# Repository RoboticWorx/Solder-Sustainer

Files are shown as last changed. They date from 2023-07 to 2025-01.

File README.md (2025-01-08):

# Solder_Sustainer
Files for my Solder Sustainer project.

Everything needed to build this project can be found on www.roboticworx.io for free! (https://roboticworx.io/blogs/projects/solder-sustainer)
Holding
MAIN

**_(Remember, you can download anything you'd like for yourself but you CAN'T sell it. All my work is licensed, thanks!)_**

Thanks for reading and happy making!

Best regards,
Justin

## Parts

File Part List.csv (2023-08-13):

 | From LCSC
Order Qty. | LCSC Part Number | Manufacture Part Number | Manufacturer | Package | Description | RoHS | Unit Price
3 | C383211 | LESD5D5.0CT1G | LRC | SOD-523 | Zener Diode 5.6V 18.6V 5V Bi-Directional SOD-523 ESD Protection Devices ROHS | YES | 0.0152
1 | C82544 | 1N5819HW-7-F | Diodes Incorporated | SOD-123 | Diode 40V 450mV@1A 1A SOD-123 Schottky Barrier Diodes (SBD) ROHS | YES | 0.0208
5 | C513772 | CS1005X7R104K500NR | Samwha Capacitor | 402 | 50V 100nF Capacitor ±10% 0402 Multilayer Ceramic Capacitors MLCC - SMD/SMT ROHS | YES | 0.0019
2 | C2912598 | HoAR0805-1/8W-5.1KR-0.1%-TCR25 | Milliohm | 805 | 5k1 Resistor 125mW Ceramic resistor ±25ppm/℃ ±0.1% 5.1kΩ 0805 Chip Resistor - Surface Mount ROHS | YES | 0.0506
1 | *OPTIONAL C2886570 | SK6812mini | OPSCO Optoelectronics | SMD | SMD Light Emitting Diodes (LED) ROHS | YES | 0.1927
2 | C2886903 | TL3305BF260QG | E-Switch | SMD | Switch NO 50mA 100MΩ 200000 Times 12V 260gf Brick nogging SPST SMD Tactile Switches ROHS | YES | 0.1807
1 | C2913202 | ESP32-S3-WROOM-1U-N16R8 | Espressif Systems | SMD,18x25.5mm | ESP32-S3-WROOM SMD,18x25.5mm WiFi Modules ROHS | YES | 5.1132
1 | *RESISTOR FOR PWR LED (3V3/.02A) C2849095 | PTFR0805B200RP9 | Resistor.Today | 805 | 200ohm Resistor 0.13W Thin Film Resistor ±25ppm/℃ ±0.1% 200Ω 0805 Chip Resistor - Surface Mount ROHS | YES | 0.1403
1 | C2765186 | TYPE-C 16PIN 2MD(073) | SHOU HAN | SMD | USB-C Connector 5A 1 Surface Mount 16P Female -25℃~+85℃ Type-C SMD USB Connectors ROHS | YES | 0.0523
1 | C5120765 | AMS1117-3.3V | MSKSEMI | SOT-223 | 1A Fixed 3.3V Positive 18V SOT-223 Linear Voltage Regulators (LDO) ROHS | YES | 0.0427
 | From DigiKey
 | Digi-Key Part # | Manufacturer Part Number | Description | Backorder | Unit Price
4 | 1276-6454-1-ND | CL21A106KAYNNNG | 10uF/25V Capacitor CAP CER 10UF 25V X5R 0805 | 0 | $0.07
1 | 1276-1034-1-ND | CL10A105KO8NNNC | 1uF/16V Capacitor CAP CER 1UF 16V X5R 0603 | 0 | $0.01
1 | RNCP0603FTD10K0CT-ND | RNCP0603FTD10K0 | 10kohm Resistor RES 10K OHM 1% 1/8W 0603 | 0 | $0.02
 | Other | Amazon Link
1 | 100uF Capacitor (Could also be SMD) | https://www.amazon.com/BOJACK-Electrolytic-Capacitor-Assortment-0-1uF%25EF%25BC%258D1000uF/dp/B07PBQXQNQ?amp;keywords=capacitor+kit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
2 | 2N2222 Transistors or other NPN transistor | https://www.amazon.com/BOJACK-General-Purpose-Transistors-Assortment/dp/B07T5166B8?amp;keywords=transistor+kit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
1 | A4988 Stepper Motor Driver | https://www.amazon.com/gp/product/B07BND65C8?amp;psc=1&linkId=e62621cc388ef44c6753cd39ee17c85e&camp=1789&creative=9325
1 | MT3608 Voltage Step-Up Regulator | https://www.amazon.com/gp/product/B089JYBF25?amp;psc=1&linkId=d4404d10156ef6bd04675826cf120e4c&camp=1789&creative=9325

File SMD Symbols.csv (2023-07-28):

Reference | Value | Footprint | Datasheet | SNAPEDA_PACKAGE_ID | SNAPEDA_PN | STANDARD | Qty
A1 | Pololu_Breakout_A4988 | Module:Pololu_Breakout-16_15.2x20.3mm | https://www.pololu.com/product/2980/pictures |  |  |  | 1
C1, C4, C5, C9 | 10uF/25V | Capacitor_SMD:C_0805_2012Metric_Pad1.18x1.45mm_HandSolder | ~ |  |  |  | 4
C2 | 1uF/16V | Capacitor_SMD:C_0603_1608Metric_Pad1.08x0.95mm_HandSolder | ~ |  |  |  | 1
C3, C6-C8, C10 | 0u1F/50V | Capacitor_SMD:C_0201_0603Metric_Pad0.64x0.40mm_HandSolder | ~ |  |  |  | 5
C11 | 100µF | Capacitor_THT:CP_Radial_D5.0mm_P2.50mm | ~ |  |  |  | 1
D1 | 1N5819HW-7-F | MyParts:SOD3715X145N |  |  |  | IPC-7351B | 1
D2-D4 | LESD5D5.0CT1G | MyParts:TVS_LESD5D5.0CT1G |  |  |  | Manufacturer Recommendations | 3
D5 | SK6812MINI | LED_SMD:LED_SK6812MINI_PLCC4_3.5x3.5mm_P1.75mm | https://cdn-shop.adafruit.com/product-files/2686/SK6812MINI_REV.01-1-2.pdf |  |  |  | 1
D6 | LED | LED_THT:LED_D3.0mm | ~ |  |  |  | 1
D7 | Apple Block | MyParts:Outlet Rectifier | ~ |  |  |  | 1
J1 | TYPE-C-31-M-12 | MyParts:HRO_TYPE-C-31-M-12 |  |  | TYPE-C-31-M-12 | Manufacturer Recommendations | 1
J2 | Conn_01x04_Pin | Connector_PinHeader_2.54mm:PinHeader_1x04_P2.54mm_Vertical | ~ |  |  |  | 1
Q1, Q2 | 2N2222 | Connector_PinHeader_2.00mm:PinHeader_1x03_P2.00mm_Vertical | http://www.onsemi.com/pub_link/Collateral/2N2219-D.PDF |  |  |  | 2
R1, R2 | 5k1 | Resistor_SMD:R_0805_2012Metric_Pad1.20x1.40mm_HandSolder | ~ |  |  |  | 2
R3 | 10k | Resistor_SMD:R_0805_2012Metric_Pad1.20x1.40mm_HandSolder | ~ |  |  |  | 1
R4 | 165 | Resistor_SMD:R_0603_1608Metric_Pad0.98x0.95mm_HandSolder | ~ |  |  |  | 1
S1 | TL3305BF260QG/BOOT | MyParts:SW_TL3305BF260QG |  |  | TL3305BF260QG | Manufacturer Recommendations | 1
S2 | TL3305BF260QG/RST | MyParts:SW_TL3305BF260QG |  |  | TL3305BF260QG | Manufacturer Recommendations | 1
U1 | ESP32-S3-WROOM-1-N16R2 | MyParts:XCVR_ESP32-S3-WROOM-1-N16R2 |  |  |  | Manufacturer Recommendations | 1
U2 | AMS1117-3.3 | MyParts:AMS1117-3.3 |  | 71280 | AMS1117-3.3 | IPC 7351B | 1
U3 | MT3608 | MyParts:MT3608 Breakout | https://www.olimex.com/Products/Breadboarding/BB-PWR-3608/resources/MT3608.pdf |  |  |  | 1
U4, U5 |  | MyParts:Touch Sensor |  |  |  |  | 2

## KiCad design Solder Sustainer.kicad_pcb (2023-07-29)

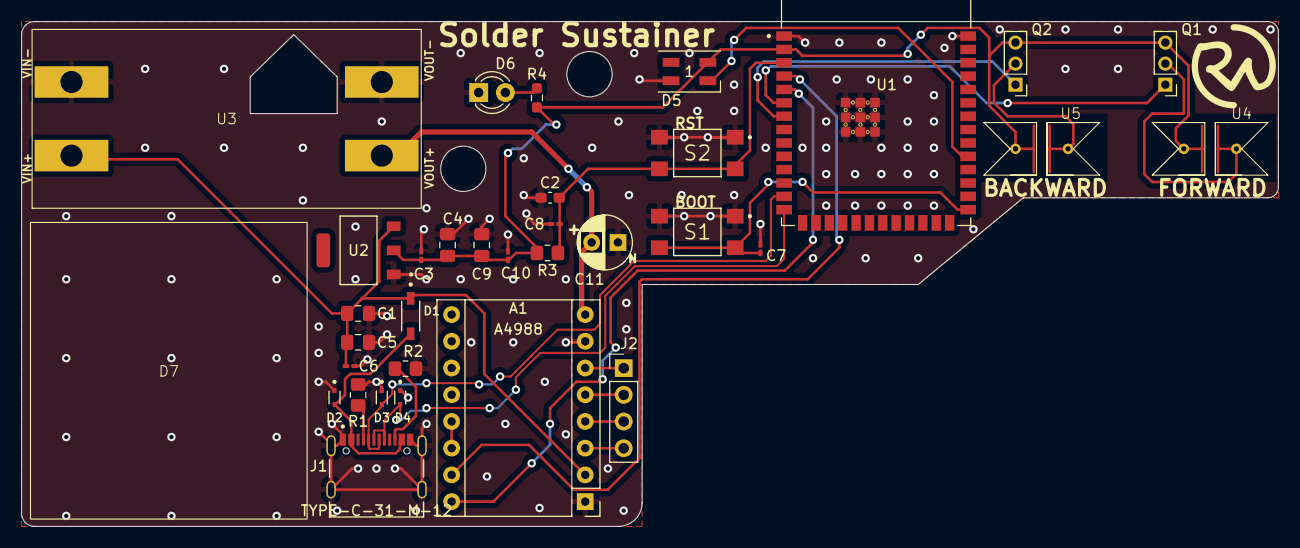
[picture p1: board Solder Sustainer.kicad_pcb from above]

Board: 2 copper layers, 119.5 x 48.0 mm, 34 parts (0 on the bottom side), 24 nets.

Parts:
A1: Pololu_Breakout_A4988; Pololu_Breakout-16_15.2x20.3mm
C1, C4, C5, C9: 10uF/25V; C_0805_2012Metric_Pad1.18x1.45mm_HandSolder
C2: 1uF/16V; C_0603_1608Metric_Pad1.08x0.95mm_HandSolder
C3, C6, C7, C8, C10: 0u1F/50V; C_0201_0603Metric_Pad0.64x0.40mm_HandSolder
C11: 100µF; CP_Radial_D5.0mm_P2.50mm
D1: 1N5819HW-7-F; SOD3715X145N
D2, D3, D4: LESD5D5.0CT1G; TVS_LESD5D5.0CT1G
D5: SK6812MINI; LED_SK6812MINI_PLCC4_3.5x3.5mm_P1.75mm
D6: LED; LED_D3.0mm
D7: Apple Block; Outlet Rectifier
J1: TYPE-C-31-M-12; HRO_TYPE-C-31-M-12
J2: Conn_01x04_Pin; PinHeader_1x04_P2.54mm_Vertical
Q1, Q2: 2N2222; PinHeader_1x03_P2.00mm_Vertical
R1, R2: 5k1; R_0805_2012Metric_Pad1.20x1.40mm_HandSolder
R3: 10k; R_0805_2012Metric_Pad1.20x1.40mm_HandSolder
R4: 165; R_0603_1608Metric_Pad0.98x0.95mm_HandSolder
S1: TL3305BF260QG/BOOT; SW_TL3305BF260QG
S2: TL3305BF260QG/RST; SW_TL3305BF260QG
U1: ESP32-S3-WROOM-1-N16R2; XCVR_ESP32-S3-WROOM-1-N16R2
U2: AMS1117-3.3
U3: MT3608; MT3608 Breakout
U4, U5: Touch Sensor

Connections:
/CC1: J1.A5 (CC1), R1.1
/CC2: J1.B5 (CC2), R2.1
B_LOW: Q2.2 (B), U5.2 (OUT)
B_STATE: Q2.1 (E), U1.7 (IO7)
CHIP_PU: C2.2, C8.1, R3.1, S2.3, S2.4, U1.3 (EN)
D+: D4.2, J1.A6 (DP1), J1.B6 (DP2), U1.14 (IO20)
D-: D3.2, J1.A7 (DN1), J1.B7 (DN2), U1.13 (IO19)
DIR: A1.16 (DIR), U1.5 (IO5)
ESP_3V3: C3.1, C4.1, C9.1, C10.1, D5.4 (VDD), Q1.3 (C), Q2.3 (C), R3.2, R4.1, U1.2 (3V3), U2.2 (VOUT), U4.1 (VCC), U5.1 (VCC)
F_LOW: Q1.2 (B), U4.2 (OUT)
F_STATE: Q1.1 (E), U1.6 (IO6)
GND: A1.1 (GND), A1.7 (GND), C1.2, C2.1, C3.2, C4.2, C5.2, C6.2, C7.2, C8.2, C9.2, C10.2, C11.1, D2.1, D3.1, D4.1, D5.2 (VSS), D6.1 (K), J1.A1_B12 (GND), J1.B1_A12 (GND), J1.S1 (SHIELD), J1.S2 (SHIELD), J1.S3 (SHIELD), J1.S4 (SHIELD), R1.2, R2.2, S1.1, S1.2, S2.1, S2.2, U1.1 (GND), U1.40 (GND), U1.41_1 (GND), U1.41_2 (GND), U1.41_3 (GND), U1.41_4 (GND), U1.41_5 (GND), U1.41_6 (GND), U1.41_7 (GND), U1.41_8 (GND), U1.41_9 (GND), U1.41_10, U1.41_11, U1.41_12, U1.41_13, U1.41_14, U1.41_15, U1.41_16, U1.41_17, U1.41_18, U1.41_19, U1.41_20, U1.41_21, U2.1 (GND/ADJ), U3.2 (GND), U3.3 (FB)
GPIO0: C7.1, S1.3, S1.4, U1.27 (IO0)
unnamed: A1.4 (1A), J2.3
unnamed: A1.3 (1B), J2.4
unnamed: A1.5 (2A), J2.2
unnamed: A1.6 (2B), J2.1
unnamed: A1.13 (~RESET), A1.14 (~SLEEP)
unnamed: D1.A, D2.2, J1.A4_B9 (VBUS), J1.B4_A9 (VBUS)
unnamed: D6.2 (A), R4.2
SK6812: D5.3 (DIN), U1.31 (IO38)
STEP: A1.15 (STEP), U1.4 (IO4)
VCC_5V: A1.2 (VDD), C1.1, C5.1, C6.1, D1.C, U2.3 (VIN), U3.5 (IN)
VMOT: A1.8 (VMOT), C11.2, U3.1 (SW)

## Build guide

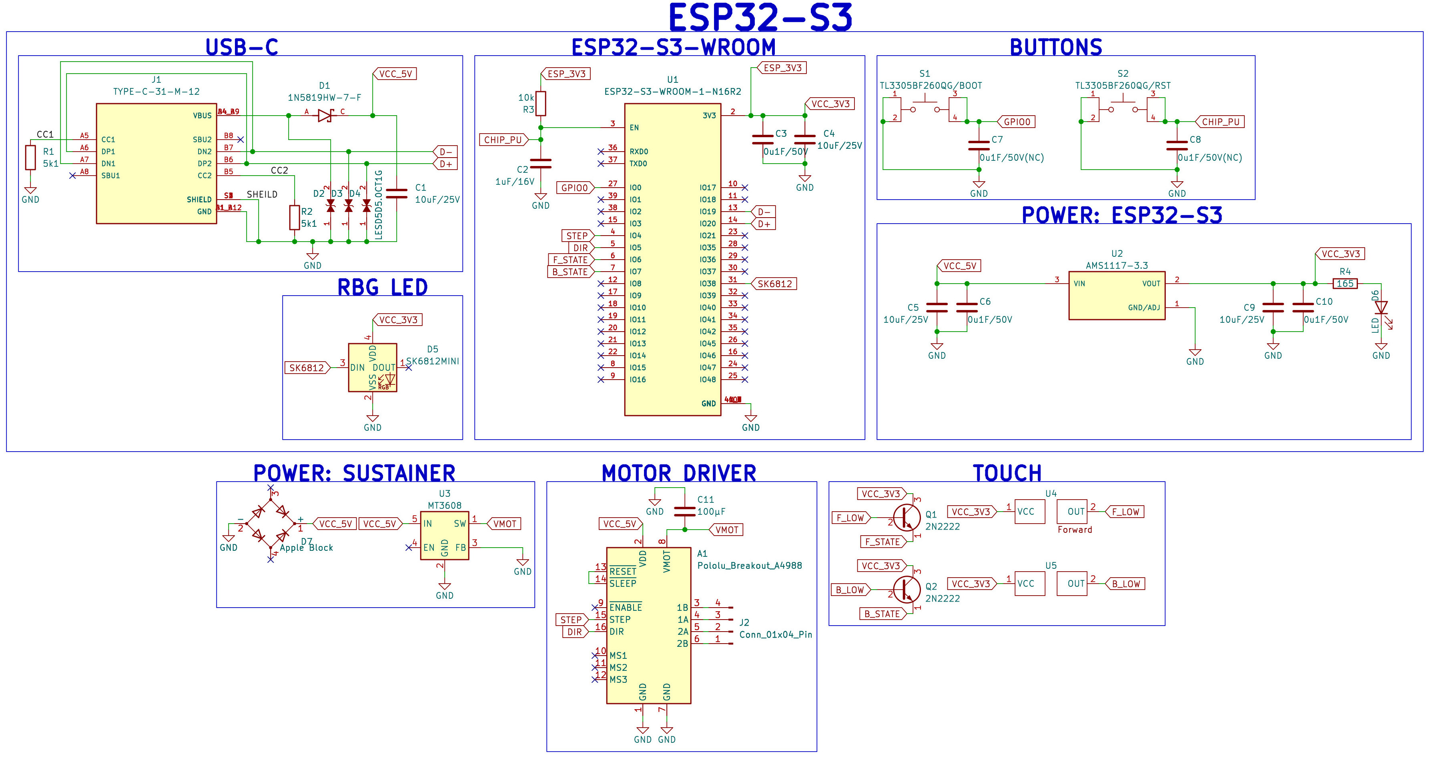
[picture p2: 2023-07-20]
Solder Sustainer.jpg

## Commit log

2023-07-20 Add files via upload
    KiCad Schematic file.
    [Solder Sustainer.kicad_sch]
2023-07-20 SMD BOM
    SMD components description, values, footprints, and more.
    [Solder Sustainer.csv]
2023-07-26 Fabrication File for the PCB
2023-07-27 Solder Sustainer Gerber File For Fabrication
2023-07-27 Gerber File for Fabrication
2023-07-27 Wiring Schematic (Image)
2023-07-27 KiCad Files for Schematic and PCB
    [Solder Sustainer.kicad_pcb, Solder Sustainer.kicad_sch]
2023-07-27 The Program
    Program for my solder sustainer project
2023-07-28 Component Part List
    [Part List.csv]
2023-07-28 SMD Symbols For PCB Assembly
    [SMD Symbols.csv]
2023-08-13 Update Part List.csv
    [Part List.csv]
